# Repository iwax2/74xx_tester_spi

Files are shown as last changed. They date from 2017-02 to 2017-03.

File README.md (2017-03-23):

# 74xx_tester_spi

電気系の実験で用いる74LSxxシリーズ、学校の実験で壊れているかどうかチェックするのが大変なので、簡単にテストできるテス
タを作りました。
Arduinoシールド型（ちょっとでかい）で、0.5秒ぐらいでICを1つテストできます。
これはSPIでI/Oエキスパンダ(MCP23S17-E/SP)を接続するバージョンです。I2Cの(MCP23017-E/SP)も作る予定。

## つかうもの
* Arduino uno(互換品でも可)
* MCP23S17-E/SP(<http://akizukidenshi.com/catalog/g/gI-10644/>)
* ArduinoのLiquidCrystalクラスが使えるLCD(SC162Cなど)
* 14pin以上のソケット(できればゼロプレッシャー) こんなの -> <http://www.aitendo.com/product/12374>
* タクトスイッチ2つ
* Arduinoシールド台（基板加工機を使って作る、PCB製造業者に依頼する、自分でエッチングする、Arduino用のユニバーサル基板シールドを加工する、[ユニバーサル](http://diary-kuzenikike.blogspot.jp/2010/03/arduino.html "Arduino用のユニバーサル基板をつくる")[基板Cで頑張る](http://memo.tank.jp/archives/1182 "頑丈な自作プロトシールド")　など）

## 対応IC
*  "IV1 (74LS04)", // 1-input NOT
*  "AN2 (74LS08)", // 2-input AND
*  "OR2 (74LS32)", // 2-input OR
*  "ND2 (74LS00)", // 2-input NAND
*  "NR2 (74LS02)", // 2-input NOR
*  "EO2 (74LS86)", // 2-input XOR
*  "DFF (74LS74)"  // D flip-flop

## つかいかた
1. Arduinoにシールドを指します
2. テストしたいICをゼロプレッシャーソケットにセットします
3. セットしたICの型番をselectボタンで選択します
4. testボタンを押して、OKが出れば正常、NGが出れば壊れています

## Arduinoへのスケッチの書き込み
`tester_74xx_spi.ino`をArduino IDE (1.6.11で確認)で書き込んでください

## demo
demo

## Pictures
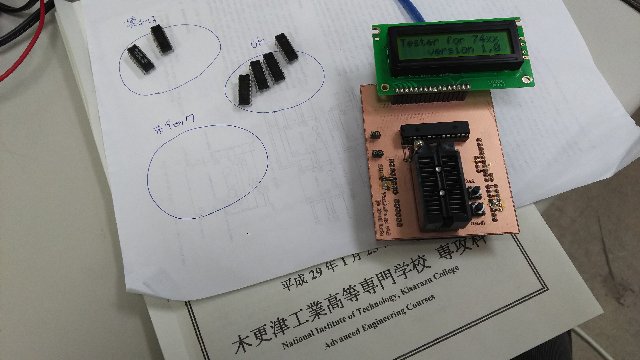
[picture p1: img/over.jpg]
全体写真
  

全体写真

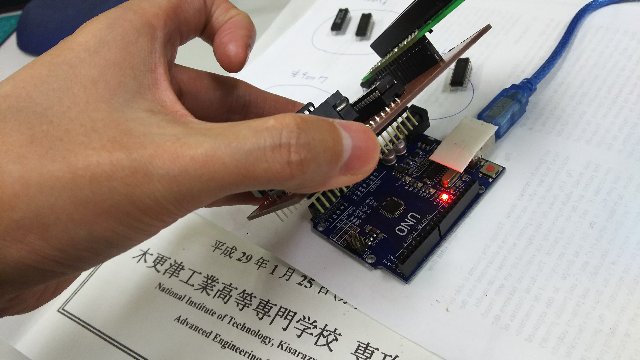
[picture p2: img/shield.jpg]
Arduinoシールドとして利用できる
  

Arduinoシールドとして利用できる

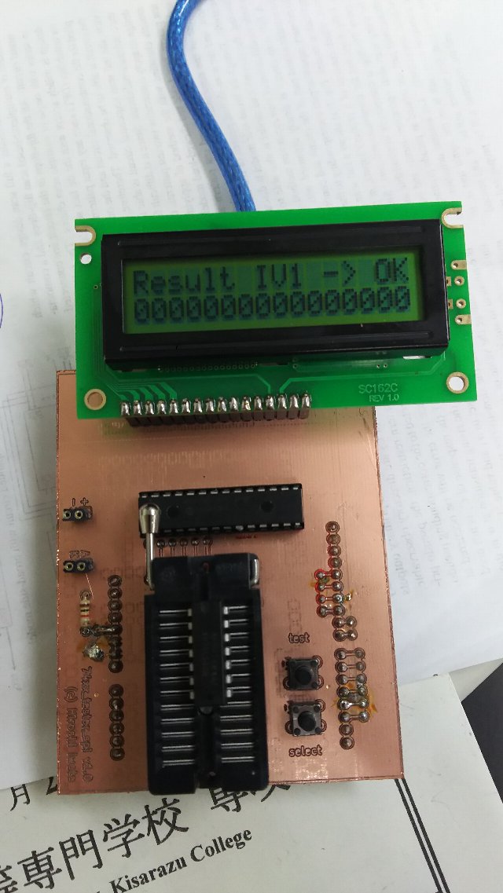
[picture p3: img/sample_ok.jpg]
OKの場合
  

テストした結果がOKの場合（壊れていないIC）

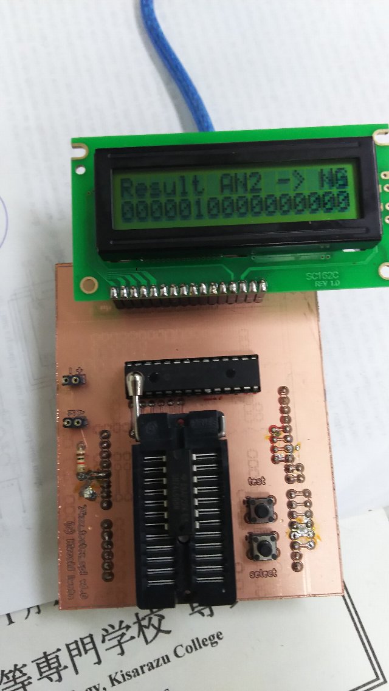
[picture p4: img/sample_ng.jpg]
NGの場合
 

テストした結果がNGの場合（壊れているIC）

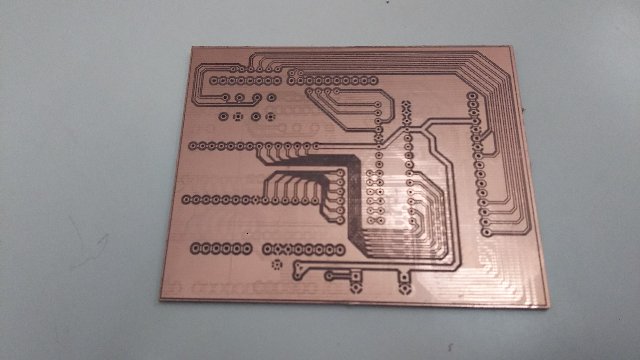
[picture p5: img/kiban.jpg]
加工した基板の例
  

基板加工機(MITS AutoLab)で作成

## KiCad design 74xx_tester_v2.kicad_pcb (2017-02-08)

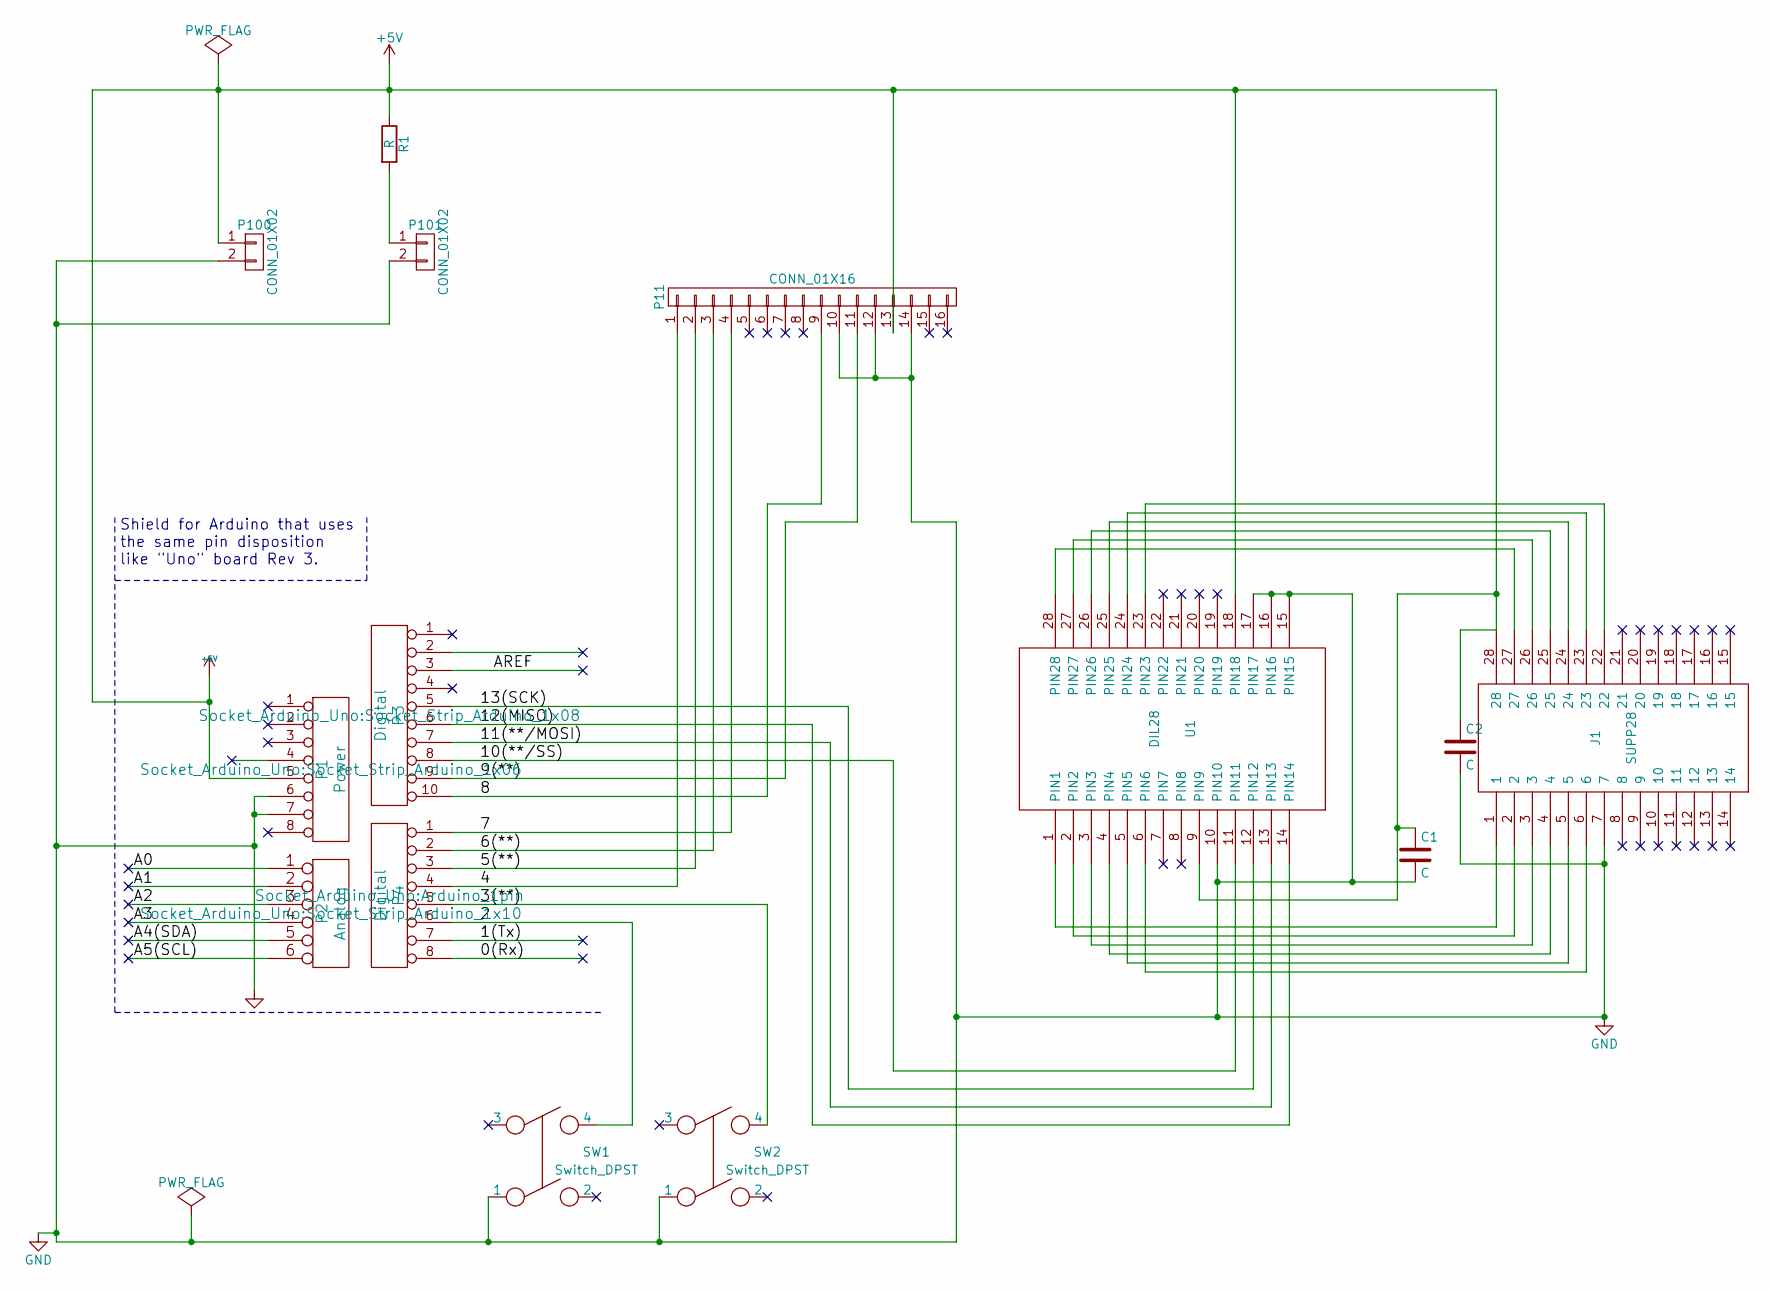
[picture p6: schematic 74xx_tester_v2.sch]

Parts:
C1, C2: C; C_0805_HandSoldering
J1: SUPP28; DIP-28_W15.24mm
P1: Power; Socket_Strip_Arduino_1x06
P2: Analog; Socket_Strip_Arduino_1x10
P3: Digital; Socket_Strip_Arduino_1x08
P4: Digital; Arduino_1pin
P11: CONN_01X16; Socket_Strip_Straight_1x16
P100, P101: CONN_01X02; Socket_Strip_Straight_1x02
R1: R; R_Axial_DIN0411_L9.9mm_D3.6mm_P7.62mm_Vertical
SW1, SW2: Switch_DPST; SW_TH_Tactile_Omron_B3F-10xx
U1: DIL28; DIP-28_W7.62mm

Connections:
+5V: C1.1, C2.1, J1.28, P1.5, P11.13, P100.1, R1.1, U1.9 (PIN9), U1.18 (PIN18)
/0(Rx): P4.8
/1(Tx): P4.7
/2: P4.6, SW1.4
/3(**): P4.5, SW2.4
/4: P4.4, P11.1
/5(**): P4.3, P11.2
/6(**): P4.2, P11.3
/7: P4.1, P11.4
/8: P3.10, P11.9
/9(**): P3.9, P11.11
/10(**/SS): P3.8, U1.11 (PIN11)
/11(**/MOSI): P3.7, U1.13 (PIN13)
/12(MISO): P3.6, U1.14 (PIN14)
/13(SCK): P3.5, U1.12 (PIN12)
/A0: P2.1
/A1: P2.2
/A2: P2.3
/A3: P2.4
/A4(SDA): P2.5
/A5(SCL): P2.6
/AREF: P3.3
GND: C1.2, C2.2, J1.7, P1.6, P1.7, P11.10, P11.12, P11.14, P100.2, P101.2, SW1.1, SW2.1, U1.10 (PIN10), U1.15 (PIN15), U1.16 (PIN16), U1.17 (PIN17)
unnamed: J1.1, U1.1 (PIN1)
unnamed: J1.2, U1.2 (PIN2)
unnamed: J1.3, U1.3 (PIN3)
unnamed: J1.4, U1.4 (PIN4)
unnamed: J1.5, U1.5 (PIN5)
unnamed: J1.6, U1.6 (PIN6)
unnamed: J1.22, U1.23 (PIN23)
unnamed: J1.23, U1.24 (PIN24)
unnamed: J1.24, U1.25 (PIN25)
unnamed: J1.25, U1.26 (PIN26)
unnamed: J1.26, U1.27 (PIN27)
unnamed: J1.27, U1.28 (PIN28)
unnamed: P101.1, R1.2

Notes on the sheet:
Shield for Arduino that uses the same pin disposition like "Uno" board Rev 3.

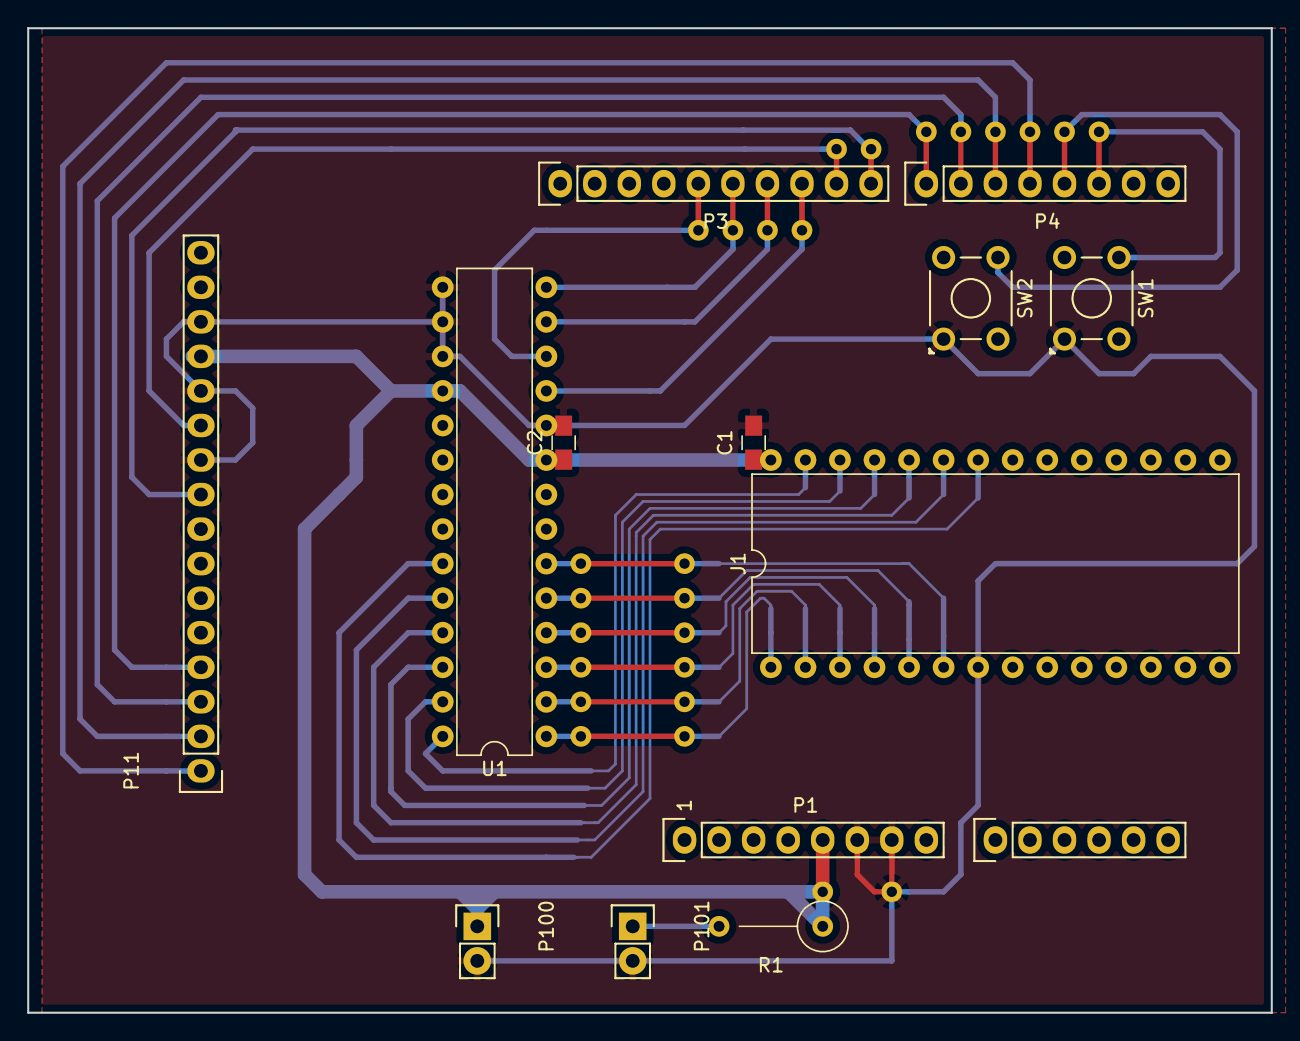
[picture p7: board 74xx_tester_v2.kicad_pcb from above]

Board: 2 copper layers, 91.4 x 72.4 mm, 14 parts (0 on the bottom side), 27 nets.

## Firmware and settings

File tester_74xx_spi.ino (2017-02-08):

#define MOSI 11 // Master Output Slave Input
#define MISO 12 // Master Input Slave Output
#define SCLK 13 // SPI clock
#define SSEL 10 // Slave Select

#define SW_IC_SELECT 2
#define SW_TEST_START 3

#define GPIOA 0x12
#define GPIOB 0x13

// inslude the SPI library:
#include <SPI.h>
// include the library code:
#include <LiquidCrystal.h>

// initialize the library with the numbers of the interface pins
//LiquidCrystal lcd(8, 9, 4, 5, 6, 7);
LiquidCrystal lcd(9, 8, 7, 6, 5, 4);

#define NO_TYPES 7
char* ic_type[] = {
  "IV1 (74LS04)", // 1-input NOT
  "AN2 (74LS08)", // 2-input AND
  "OR2 (74LS32)", // 2-input OR
  "ND2 (74LS00)", // 2-input NAND
  "NR2 (74LS02)", // 2-input NOR
  "EO2 (74LS86)", // 2-input XOR
  "DFF (74LS74)"  // D flip-flop
  // JK flip-flopは16pinだからテストできねぇｗ
};

/*
    74LSxxの各pinへ
    13 12 11 10  9  8                   VDD GND  GND  GND
     |  |  |  |  |  |  |  |   |    |     |   |    |    |
   +-+--+--+--+--+--+--+--+---+----+-----+---+----+----+---+
   | A7 A6 A5 A4 A3 A2 A1 A0 INTA INTB ^RES ADR2 ADR1 ADR0 |
   |                                                       |
   |>                       MCP23S17                       |
   |                                                       |
   | B0 B1 B2 B3 B4 B5 B6 B7 VDD  GND   ^CS SCK  SI   SO  .|
   +-+--+--+--+--+--+--+--+---+----+-----+---+----+----+---+
     |  |  |  |  |  |  |  |   |    |     |   |    |    |
     1  2  3  4  5  6        VDD  GND    10  13   11   12
    74LSxxの各pinへ                      Arduinoの各pinへ

   SPI receive format (16bit)
   Bit   | [15][14][13][12][11][10][9] [8] [7] [6] [5] [4] [3] [2] [1] [0]
  Name   |  A7  A6  A5  A4  A3  A2  A1  A0  B7  B6  B5  B4  B3  B2  B1  B0
  74pin  |  13  12  11  10   9   8                   6   5   4   3   2   1
  ND2_DIR| out out  in out out  in                  in out out  in out out
  NR2_DIR|  in out out  in out out                 out out  in out out  in
  IV1_DIR| out  in out  in out  in                  in out  in out  in out
  DFF_DIR| out out out out  in  in                  in  in out out out out
*/
// bit number        5432109876543210
#define ND2_IO_DIR 0b0010011111100100 // I/O Direction 0:output 1:input
#define NR2_IO_DIR 0b1001001111001001 // I/O Direction 0:output 1:input
#define IV1_IO_DIR 0b0101011111101010 // I/O Direction 0:output 1:input
#define DFF_IO_DIR 0b0000111111110000 // I/O Direction 0:output 1:input

volatile int mode = -1;
volatile bool flag_test = false;

int lcd_mode = -1;
int pt, ct;

void setup() {
  lcd.begin(16, 2);  // set columns and rows of LCD
  lcd.setCursor(0, 0);
  lcd.print("Tester for 74xx"); // max 16 character
  lcd.setCursor(0, 1);
  lcd.print("    version 1.0 ");

  // set switch direction
  pinMode(SW_IC_SELECT, INPUT_PULLUP);
  pinMode(SW_TEST_START, INPUT_PULLUP);
  attachInterrupt(digitalPinToInterrupt(SW_IC_SELECT), change_mode, FALLING);
  attachInterrupt(digitalPinToInterrupt(SW_TEST_START), start_test, FALLING);

  // set the slaveSelectPin as an output:
  pinMode(SSEL, OUTPUT);
  SPI.begin();
  write_SPI_port(0x0A, 0b00000000); // IOCON – I/O EXPANDER CONFIGURATION REGISTER
  write_SPI_port(0x0C, 0b11111111); // GPPUA – PULL-UP RESISTOR CONFIGURATION REGISTER BANK=0
  write_SPI_port(0x0D, 0b11111111); // GPPUB – PULL-UP RESISTOR CONFIGURATION REGISTER BANK=0
  write_SPI_port(0x00, 0b11111111); // I/O Direction A 0:output 1:input (Default : input)
  write_SPI_port(0x01, 0b11111111); // I/O Direction B 0:output 1:input プルアップしてるから安全かなと

  Serial.begin(9600);
  delay(100);
  flag_test = false;
}

void loop() {
//  Serial.println(flag_test);
  if ( lcd_mode != mode ) {
    lcd_print_mode();
    flag_test = false;
  }

  if ( flag_test == true ) {
    flag_test = false;
    lcd_print_mode();
    delay(500);
    exec_test(); // test execution
//    delay(1000);
    // テストが終わったら全ピンをinputに変えて安全にしておく
    write_SPI_port(0x00, 0b11111111); // I/O Direction A 0:output 1:input (Default : input)
    write_SPI_port(0x01, 0b11111111); // I/O Direction B 0:output 1:input プルアップしてるから安全かなと
    flag_test = false;
  } else {
    delay(200);
  }
}

void exec_test() {
  unsigned int response = 0x0000; // 0: OK / 1: NG
  char selected_ic = (char*)malloc(sizeof(char) * 4);
  Serial.print("Test start -> ");
  selected_ic = get_ic_name3(selected_ic, mode);
  if ( strcmp(selected_ic, "IV1") == 0 ) {
    Serial.println("NOT");
    response |= apply_to_1input1(0, 1);
    response |= apply_to_1input1(1, 0);
  } else if ( strcmp(selected_ic, "AN2") == 0 ) {
    Serial.println("AND");
    response |= apply_to_2input1(0, 0, 0);
    response |= apply_to_2input1(0, 1, 0);
    response |= apply_to_2input1(1, 0, 0);
    response |= apply_to_2input1(1, 1, 1);
  } else if ( strcmp(selected_ic, "OR2") == 0 ) {
    Serial.println("OR");
    response |= apply_to_2input1(0, 0, 0);
    response |= apply_to_2input1(0, 1, 1);
    response |= apply_to_2input1(1, 0, 1);
    response |= apply_to_2input1(1, 1, 1);
  } else if ( strcmp(selected_ic, "ND2") == 0 ) {
    Serial.println("NAND");
    response |= apply_to_2input1(0, 0, 1);
    response |= apply_to_2input1(0, 1, 1);
    response |= apply_to_2input1(1, 0, 1);
    response |= apply_to_2input1(1, 1, 0);
  } else if ( strcmp(selected_ic, "EO2") == 0 ) {
    Serial.println("XOR");
    response |= apply_to_2input1(0, 0, 0);
    response |= apply_to_2input1(0, 1, 1);
    response |= apply_to_2input1(1, 0, 1);
    response |= apply_to_2input1(1, 1, 0);
  } else if ( strcmp(selected_ic, "NR2") == 0 ) {
    Serial.println("NOR");
    response |= apply_to_2input2(0, 0, 1);
    response |= apply_to_2input2(0, 1, 0);
    response |= apply_to_2input2(1, 0, 0);
    response |= apply_to_2input2(1, 1, 0);
  } else if ( strcmp(selected_ic, "DFF") == 0 ) {
    Serial.println("DFF");   // cl re se d  q  qn
    response |= apply_to_4input1(0, 0, 1, 0, 0, 1); // reset
    response |= apply_to_4input1(0, 1, 0, 0, 1, 0); // set
    response |= apply_to_4input1(0, 1, 1, 0, 1, 0); // interval
    response |= apply_to_4input1(1, 1, 1, 0, 0, 1); // positive edge triger D=1->0
    response |= apply_to_4input1(0, 1, 1, 0, 0, 1); // interval
    response |= apply_to_4input1(1, 1, 1, 0, 0, 1); // positive edge triger D=0->0
    response |= apply_to_4input1(1, 1, 1, 1, 0, 1); // hold
    response |= apply_to_4input1(0, 1, 1, 1, 0, 1); // interval
    response |= apply_to_4input1(1, 1, 1, 1, 1, 0); // positive edge triger D=0->1
    response |= apply_to_4input1(0, 1, 1, 1, 1, 0); // interval
    response |= apply_to_4input1(1, 1, 1, 1, 1, 0); // positive edge triger D=1->1
    response |= apply_to_4input1(1, 1, 1, 0, 1, 0); // hold
    response |= apply_to_4input1(1, 0, 1, 0, 0, 1); // reset
  } else {
    response = 0xffff;
  }
  Serial.println("end!");
  if ( response == 0 ) {
    lcd_print_result("OK", response);
  } else {
    lcd_print_result("NG", response);
  }
  Serial.println("");
}

// ND2, AN2, OR2, EO2
unsigned int apply_to_2input1( byte test_a, byte test_b, byte expect ) {
  unsigned int a = (test_a << 15) | (test_a << 12) | (test_a << 4) | (test_a << 1); // 13pin 10pin 5pin 2pin (74LS00)
  unsigned int b = (test_b << 14) | (test_b << 11) | (test_b << 3) | (test_b << 0); // 12pin  9pin 4pin 1pin (74LS00)
  unsigned int e = (expect << 13) | (expect << 10) | (expect << 5) | (expect << 2); // 11pin  8pin 6pin 3pin (74LS00)
  return apply_test( (~ND2_IO_DIR & (a | b)), e, ND2_IO_DIR );
}
// NR2
unsigned int apply_to_2input2( byte test_a, byte test_b, byte expect ) {
  unsigned int a = (test_a << 13) | (test_a << 10) | (test_a << 5) | (test_a << 2); // 11pin  8pin 6pin 3pin (74LS02)
  unsigned int b = (test_b << 14) | (test_b << 11) | (test_b << 4) | (test_b << 1); // 12pin  9pin 5pin 2pin (74LS02)
  unsigned int e = (expect << 15) | (expect << 12) | (expect << 3) | (expect << 0); // 13pin 10pin 4pin 1pin (74LS02)
  return apply_test( (~NR2_IO_DIR & (a | b)), e, NR2_IO_DIR );
}
// IV1
unsigned int apply_to_1input1( byte test_a, byte expect ) {
  unsigned int a = (test_a << 15) | (test_a << 13) | (test_a << 11) | (test_a << 4) | (test_a << 2) | (test_a << 0); // 13pin 11pin 9pin 5pin 3pin 1pin (74LS04)
  unsigned int e = (expect << 14) | (expect << 12) | (expect << 10) | (expect << 5) | (expect << 3) | (expect << 1); // 12pin 10pin 8pin 6pin 4pin 2pin (74LS04)
  return apply_test( (~IV1_IO_DIR & a), e, IV1_IO_DIR );
}
// DFF (74LS74)
unsigned int apply_to_4input1( byte test_clk, byte test_clr, byte test_pr, byte test_d, byte exp_q, byte exp_pn ) {
  unsigned int a = (test_clk << 13) | (test_clk << 2); // 11pin 3pin (74LS74)
  unsigned int b = (test_clr << 15) | (test_clr << 0); // 13pin 1pin (74LS74)
  unsigned int c = (test_pr  << 12) | (test_pr  << 3); // 10pin 4pin (74LS74)
  unsigned int d = (test_d   << 14) | (test_d   << 1); // 12pin 2pin (74LS74)
  unsigned int e = (exp_q    << 11) | (exp_q    << 4); //  9pin 5pin (74LS74)
  unsigned int f = (exp_qn   << 10) | (exp_qn   << 5); //  8pin 6pin (74LS74)
  return apply_test( (~DFF_IO_DIR & (a|b|c|d)), (e|f), DFF_IO_DIR );
}
unsigned int apply_test( unsigned test, unsigned e, unsigned io_dir ) {
  write_SPI_port(0x00, byte(io_dir >> 8)); // I/O Direction A 0:output 1:input
  write_SPI_port(0x01, byte(io_dir));      // I/O Direction B 0:output 1:input
  write_SPI_port(GPIOA, test >> 8); // テストパターンが入ったA7-A0をエキスパンダに転送
  write_SPI_port(GPIOB, test >> 0); // テストパターンが入ったB7-B0をエキスパンダに転送
  delay(100);
  unsigned int data = read_SPI_port();
  unsigned int response = data & io_dir & 0b1111110000111111; // 出力応答だけ取り出す
  unsigned int result = response ^ e;        // 期待値とのxorをとって誤ってたら1で残る
  /*
    Serial.println("");
    serial_print_bin("Test:", test);
    serial_print_bin("Exp: ", e);
    serial_print_bin("Rspn:", response);
  */
  //  serial_print_bin("IODI:", io_dir);
  //  serial_print_bin("Data:", data);
  //  serial_print_bin("Rslt:", result);

  return result;
}


void serial_print_bin( char* note, unsigned int data) {
  char str[17];
  Serial.print(note);
  for ( int i = 15 ; i >= 0; i-- ) {
    str[i] = (data & 1 << i) ? '1' : '0';
  }
  str[16] = '\0';
  Serial.println(str);
  //  Serial.println(data, BIN);
}


char* int2bin_by_str( char* str, unsigned int data) {
  for ( int i = 15 ; i >= 0; i-- ) {
    str[i] = (data & 1 << i) ? '1' : '0';
  }
  str[16] = '\0';
}

void lcd_print_mode() {
  char str[17];
  lcd.setCursor(0, 0);
  lcd.print(   "Tester for 74xx "); // max 16 character
  lcd.setCursor(0, 1);
  sprintf(str, " -> %s", ic_type[mode]);
  str[16] = '\0';
  //  Serial.println(str);
  lcd.print(str);
  lcd_mode = mode;
}

void lcd_print_result( char* result, unsigned int response ) {
  char str[17];
  lcd.setCursor(0, 0);
  sprintf(str, "Result %c%c%c -> %s", ic_type[mode][0], ic_type[mode][1], ic_type[mode][2], result);
  str[16] = '\0';
  Serial.println(str);
  lcd.print(str);
  lcd.setCursor(0, 1);
  int2bin_by_str(str, response);
  lcd.print(str);
}

char* get_ic_name3( char* str_type, int type ) {
  //  strncpy( str_type, ic_type[type], 3 );
  str_type[0] = ic_type[type][0];
  str_type[1] = ic_type[type][1];
  str_type[2] = ic_type[type][2];
  str_type[3] = '\0';
  return str_type;
}

// SPI I/O expander function
void write_SPI_port(int address, byte value) {
  digitalWrite(SSEL, LOW); // start transmittion -> active low
  SPI.transfer(0b01000000); // write op code (0100_A2_A1_A0_RW) Read=1, Write=0
  SPI.transfer(address);
  SPI.transfer(value);
  digitalWrite(SSEL, HIGH); // end transmittion -> deactive
}
unsigned int read_SPI_port() {
  byte byte_7_0;
  byte byte_15_8;
  digitalWrite(SSEL, LOW); // start transmittion -> active low
  SPI.transfer(0b01000001); // read op code (0100_A2_A1_A0_RW) Read=1, Write=0
  SPI.transfer(GPIOA);
  byte_15_8 = SPI.transfer(0x00);
  byte_7_0  = SPI.transfer(0x00);
  digitalWrite(SSEL, HIGH); // end transmittion -> deactive
  return ( (int)byte_15_8 << 8 | (int)byte_7_0 ); // 読み取った値をくっつけて返す(A7-A0B7-B0)
}

// interupt
void change_mode() {
  ct = millis();
  if ( (ct - pt) > 200 ) {
    mode = (mode + 1) % NO_TYPES;
  }
  pt = ct;
  flag_test = false;
}

void start_test() {
  flag_test = true;
}

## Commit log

2017-02-08 Add files arduino source and KiCad PCB data
    [74xx_tester_v2.kicad_pcb, 74xx_tester_v2.sch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]
2017-02-08 写真を追加
